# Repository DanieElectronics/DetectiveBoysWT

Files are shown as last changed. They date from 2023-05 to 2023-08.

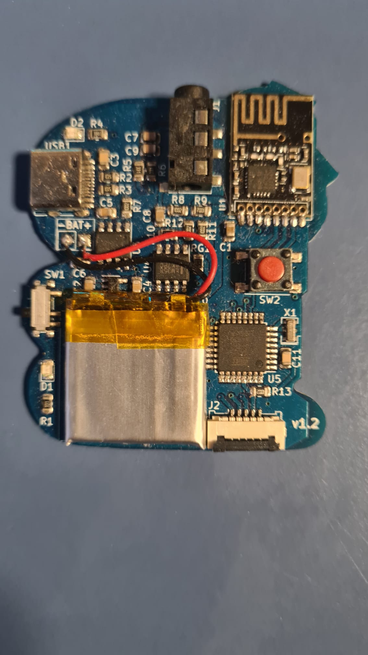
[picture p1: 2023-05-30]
board_front.jpg

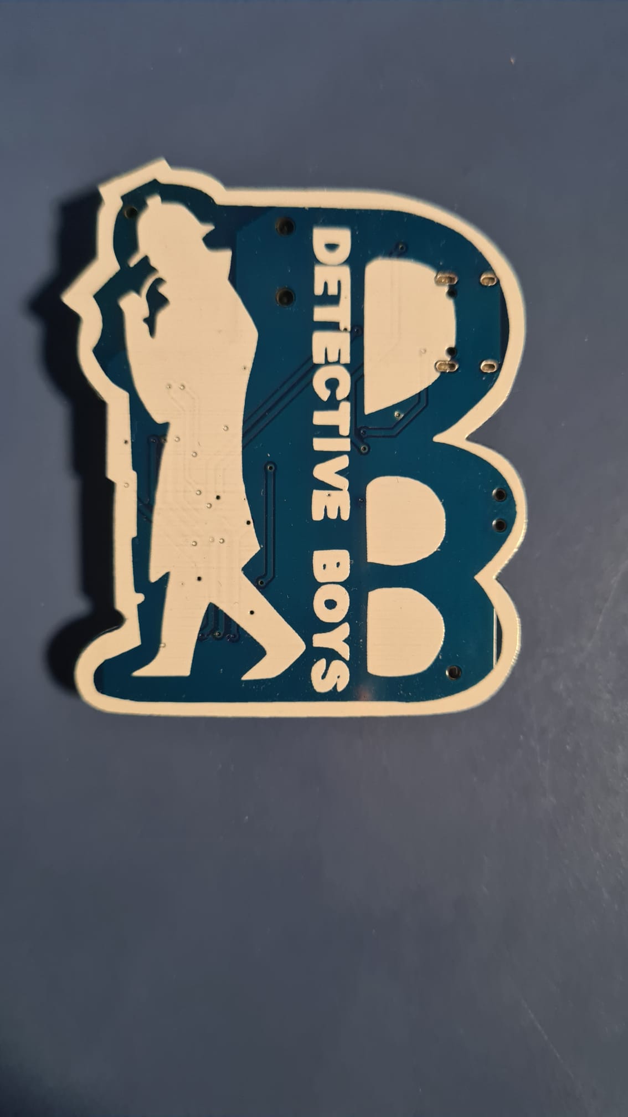
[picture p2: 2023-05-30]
board_back.jpg

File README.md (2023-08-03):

# Detective Boys walkie talkie pin badge
Walkie talkie radio pin badge inspired by Detective Conan anime series using a custom PCB and an ATMEGA328P (Arduino) microcontroller.		
Integrated rechargable battery, can be charged using any USB-C cable and USB power supply.

This repository includes the fabrication files for mounting the boards and assembling the components (gerber files, bill of materials, pick and place), as long as the code used for the microcontroller.
Keep in mind there are external components to be mounted/soldered as the battery or radio module.

## How to use
To use the walkie talkie plug any headphones with microphone into the 3.5mm audio jack, then flick the switch on the left side of the board and the LED will light up.
Press and hold the button on the board to transmit audio, all the near walkie talkies will receive and play the audio.
No pairing or previous configuration is needed.

The battery lasts around 4 hours and it can be recharged by plugging an USB-C cable, any cable or power source is compatible.
When the battery is charging, the LED near the USB connector will light up, when the battery is fully charged the LED will turn off again.
The headphones used may affect on the audio quality, try using different headphones to compare the results.

## Technical description
This project uses ATMEGA328P microcontroller on a custom PCB, the microcontrollers sends the audio data using NRF24L01 radio modules,
ATMEGA328P microcontroller works at 3.3V 8MHz, you can program it using Arduino IDE and an external programmer like USBTinyISP.

The NRF24L01 radio module is a SMD version suitable for small sized boards, it has a maximum range of 100 meters.

The LiPo battery is directly soldered into the battery terminals of the board, recommended capacity is 100-150mAh.

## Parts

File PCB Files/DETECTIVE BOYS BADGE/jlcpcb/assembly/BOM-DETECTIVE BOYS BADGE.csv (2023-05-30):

Comment | Designator | Footprint | LCSC
1k | R10,R4 | R_0805_2012Metric | C115316
ATmega328P-A | U5 | TQFP-32_7x7mm_P0.8mm | C14877
USB_C 31-M-12 | USB1 | USB_C_Receptacle_HRO_TYPE-C-31-M-12 | C165948
10uF | C1,C2,C4,C5,C6,C8 | C_0805_2012Metric | C17024
330nF | C7,C9 | C_0805_2012Metric | C1740
10k | R11,R12,R13,R7,R8,R9 | R_0805_2012Metric | C17414
470k | RG1 | R_0805_2012Metric | C17709
SPDT_PCM12 | SW1 | SW_SPDT_PCM12 | C221841
Pushbutton | SW2 | SW_SPST_PTS645 | C221871
330 | R1,R5,R6 | R_0805_2012Metric | C25306
ICSP | J2 | Molex_200528-0050_1x05-1MP_P1.00mm_Horizontal | C262360
TP4056 | U3 | SOIC-8-1EP_3.9x4.9mm_P1.27mm_EP2.29x3mm | C2763448
5.1k | R2,R3 | R_0805_2012Metric | C27834
Resonator 8MHz | X1 | Resonator_SMD_Murata_CSTxExxV-3Pin_3.0x1.1mm | C341522
MIC5205-3.3YM5 | U2 | SOT-23-5 | C37970
LED_0805 | D1,D2 | LED_0805_2012Metric | C434431
100nF | C10,C11,C3 | C_0805_2012Metric | C476766
Jack 3.5mm | J1 | Jack_3.5mm_PJ320D_Horizontal | C521460
LM358 | U4 | SOP-8_3.9x4.9mm_P1.27mm | C7950
NRF24L01_Breakout | U1 | NRF24L01_Mini
LiPo 100mAh | BT1 | PinSocket_1x02_P2.54mm_Vertical

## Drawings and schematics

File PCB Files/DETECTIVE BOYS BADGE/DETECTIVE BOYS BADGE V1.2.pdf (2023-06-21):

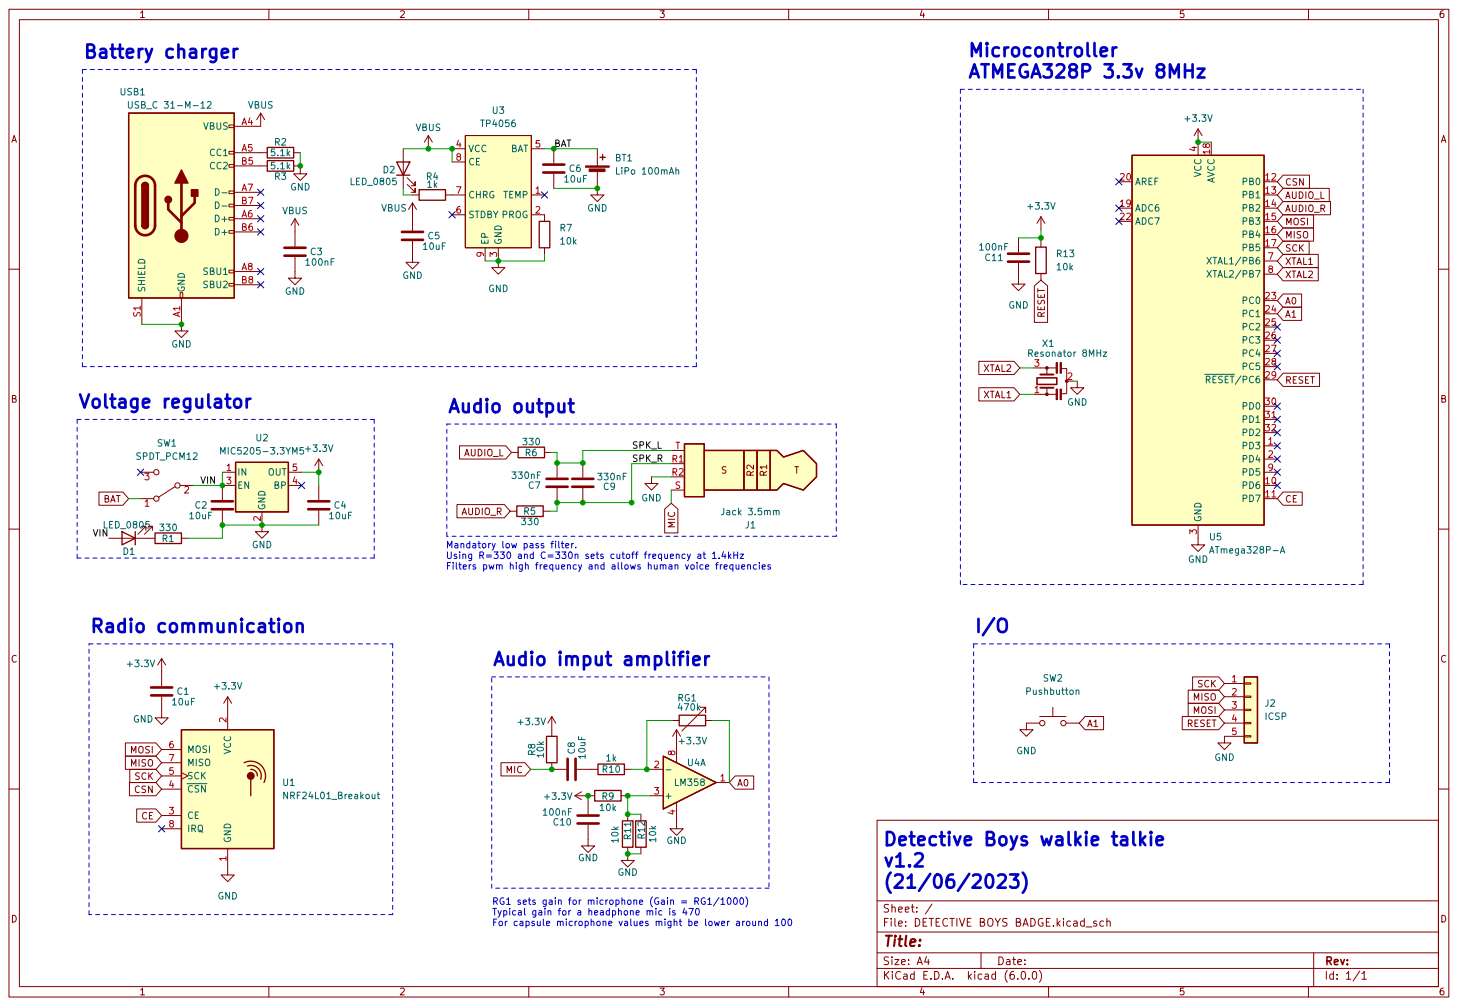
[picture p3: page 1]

3 VCC 4 BAT 5 STDBY 6 CHRG 7 CE 8 EP

2 EN 3 BP 4 OUT 5 U2 MIC5205-3.3YM5 RESET MIC

Mandatory low pass filter.
Using R=330 and C=330n sets cutoff frequency at 1.4kHz
Filters pwm high frequency and allows human voice frequencies

2 CE 3 ~{CSN} 4 SCK 5 MOSI 6 MISO 7

RG1 sets gain for microphone (Gain = RG1/1000)
Typical gain for a headphone mic is 470
For capsule microphone values might be lower around 100

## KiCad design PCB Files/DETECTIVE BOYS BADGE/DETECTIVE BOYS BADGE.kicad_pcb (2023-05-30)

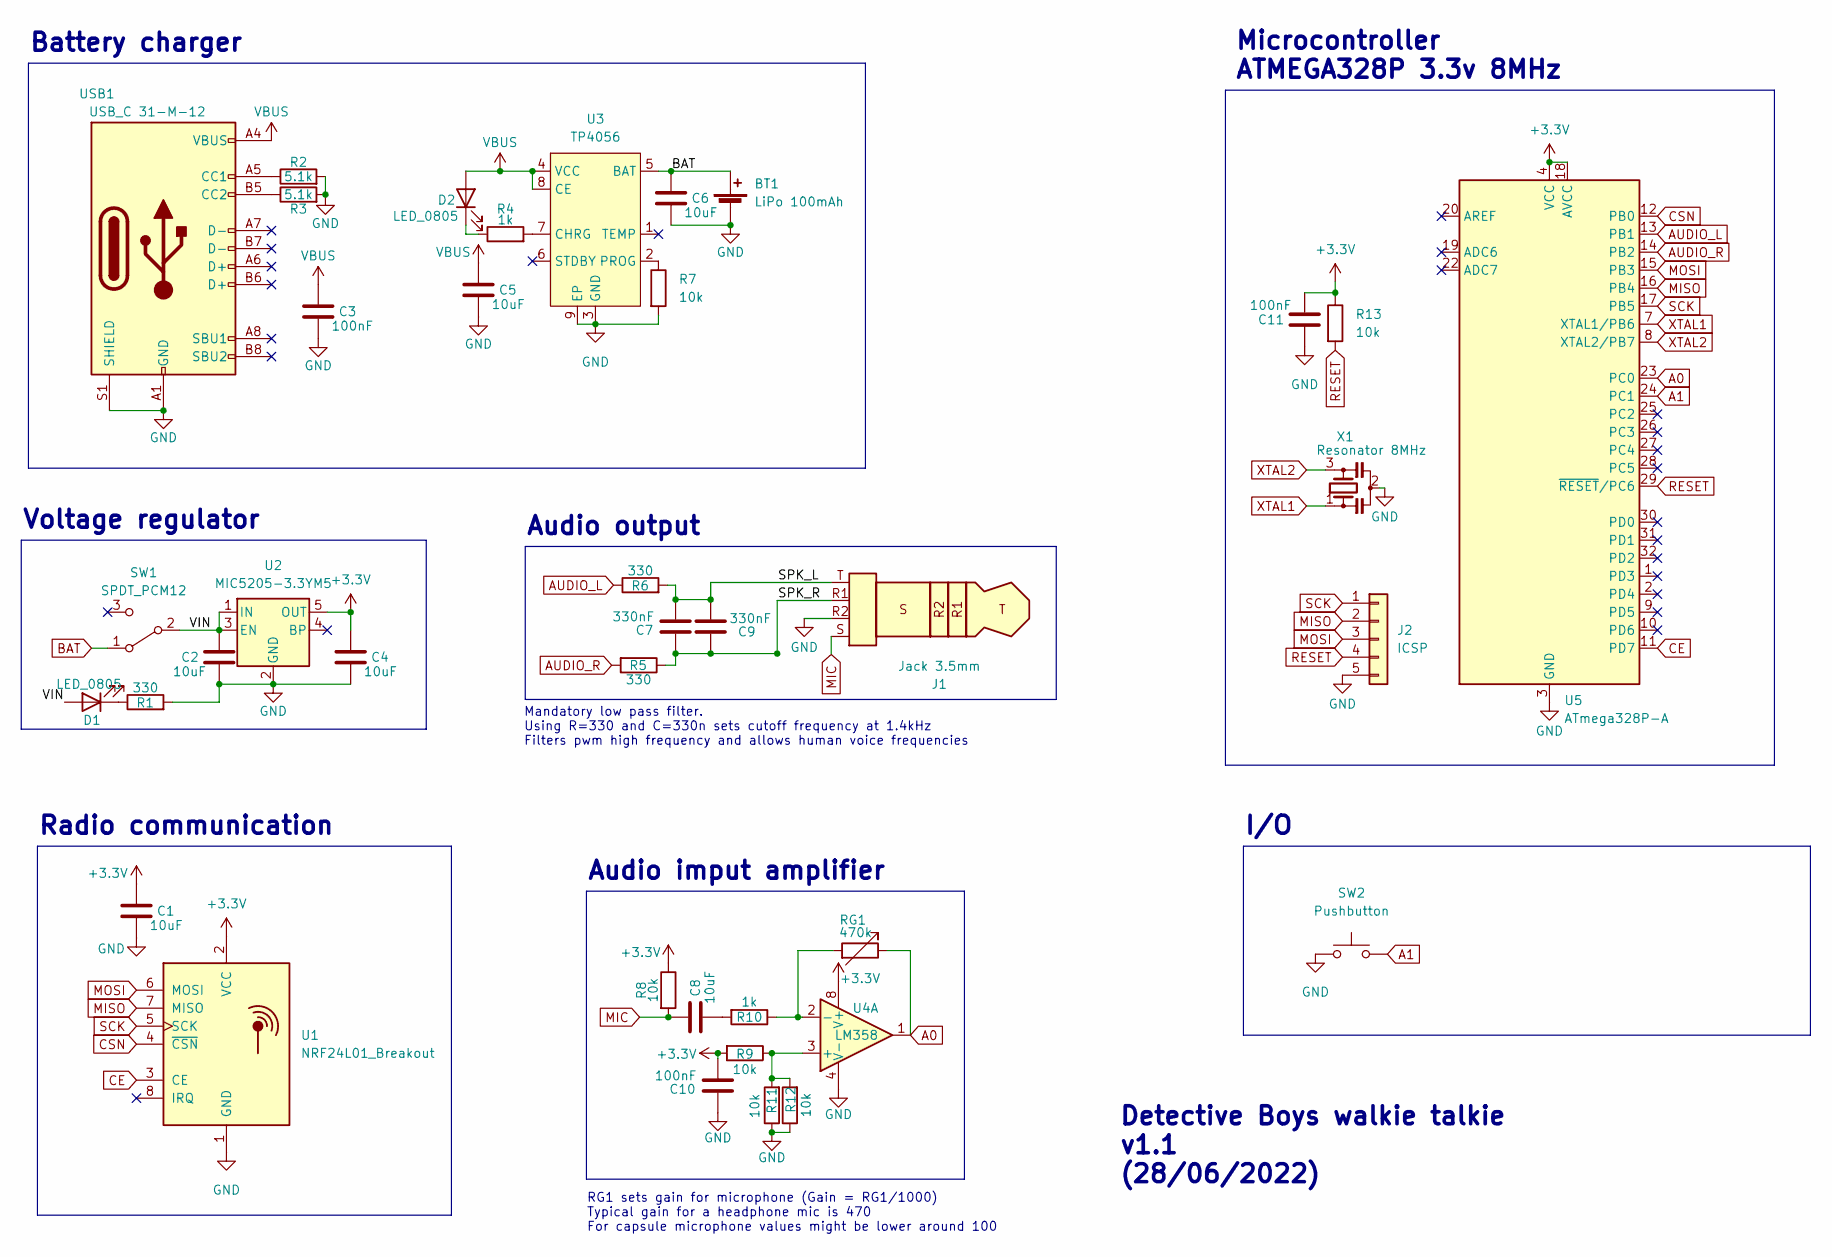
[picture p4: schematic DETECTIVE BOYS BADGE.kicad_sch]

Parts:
BT1: LiPo 100mAh; PinSocket_1x02_P2.54mm_Vertical
C1, C2, C4, C5, C6, C8: 10uF; C_0805_2012Metric
C3, C10, C11: 100nF; C_0805_2012Metric
C7, C9: 330nF; C_0805_2012Metric
D1, D2: LED_0805; LED_0805_2012Metric
J1: Jack 3.5mm; Jack_3.5mm_PJ320D_Horizontal
J2: ICSP; Molex_200528-0050_1x05-1MP_P1.00mm_Horizontal
R1, R5, R6: 330; R_0805_2012Metric
R2, R3: 5.1k; R_0805_2012Metric
R4, R10: 1k; R_0805_2012Metric
R7, R8, R9, R11, R12, R13: 10k; R_0805_2012Metric
RG1: 470k; R_0805_2012Metric
SW1: SPDT_PCM12; SW_SPDT_PCM12
SW2: Pushbutton; SW_SPST_PTS645
U1: NRF24L01_Breakout; NRF24L01_Mini
U2: MIC5205-3.3YM5; SOT-23-5
U3: TP4056; SOIC-8-1EP_3.9x4.9mm_P1.27mm_EP2.29x3mm
U4: LM358; SOP-8_3.9x4.9mm_P1.27mm
U5: ATmega328P-A; TQFP-32_7x7mm_P0.8mm
USB1: USB_C 31-M-12; USB_C_Receptacle_HRO_TYPE-C-31-M-12
X1: Resonator 8MHz; Resonator_SMD_Murata_CSTxExxV-3Pin_3.0x1.1mm

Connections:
+3V3: C1.1, C4.1, C10.2, C11.2, R8.1, R9.2, R13.1, U1.2 (VCC), U2.5 (OUT), U4.8 (V+), U5.4 (VCC), U5.6 (VCC), U5.18 (AVCC)
/SPK_L: C7.2, C9.2, J1.T, R6.2
/SPK_R: C7.1, C9.1, J1.R1, R5.1
/VIN: C2.1, D1.2 (A), SW1.2 (B), U2.1 (IN), U2.3 (EN)
A0: RG1.1, U4.1, U5.23 (PC0)
A1: SW2.2, U5.24 (PC1)
AUDIO_L: R6.1, U5.13 (PB1)
AUDIO_R: R5.2, U5.14 (PB2)
BAT: BT1.1 (+), C6.1, SW1.1 (A), U3.5 (BAT)
CE: U1.3 (CE), U5.11 (PD7)
CSN: U1.4 (~CSN), U5.12 (PB0)
GND: BT1.2 (-), C1.2, C2.2, C3.2, C4.2, C5.2, C6.2, C10.1, C11.1, J1.R2, J2.5, R1.2, R2.2, R3.2, R7.2, R11.1, R12.1, SW2.1, U1.1 (GND), U2.2 (GND), U3.3 (GND), U3.9 (EP), U4.4 (V-), U5.3 (GND), U5.5 (GND), U5.21 (GND), USB1.A1 (GND), USB1.A12 (GND), USB1.B1 (GND), USB1.B12 (GND), USB1.S1 (SHIELD), X1.2
MIC: C8.1, J1.S, R8.2
MISO: J2.2, U1.7 (MISO), U5.16 (PB4)
MOSI: J2.3, U1.6 (MOSI), U5.15 (PB3)
unnamed: C8.2, R10.2
unnamed: D1.1 (K), R1.1
unnamed: D2.1 (K), R4.1
unnamed: R2.1, USB1.A5 (CC1)
unnamed: R3.1, USB1.B5 (CC2)
unnamed: R4.2, U3.7 (CHRG)
unnamed: R7.1, U3.2 (PROG)
unnamed: R10.1, RG1.2, U4.2 (-)
unnamed: R9.1, R11.2, R12.2, U4.3 (+)
RESET: J2.4, R13.2, U5.29 (~RESET/PC6)
SCK: J2.1, U1.5 (SCK), U5.17 (PB5)
VBUS: C3.1, C5.1, D2.2 (A), U3.4 (VCC), U3.8 (CE), USB1.A4 (VBUS), USB1.A9 (VBUS), USB1.B4 (VBUS), USB1.B9 (VBUS)
XTAL1: U5.7 (XTAL1/PB6), X1.1
XTAL2: U5.8 (XTAL2/PB7), X1.3

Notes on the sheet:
Battery charger
Audio imput amplifier
Mandatory low pass filter. Using R=330 and C=330n sets cutoff frequency at 1.4kHz Filters pwm high frequency and allows human voice frequencies
I/O
RG1 sets gain for microphone (Gain = RG1/1000) Typical gain for a headphone mic is 470 For capsule microphone values might be lower around 100
Radio communication
Microcontroller ATMEGA328P 3.3v 8MHz
Audio output
Detective Boys walkie talkie v1.1 (28/06/2022)
Voltage regulator

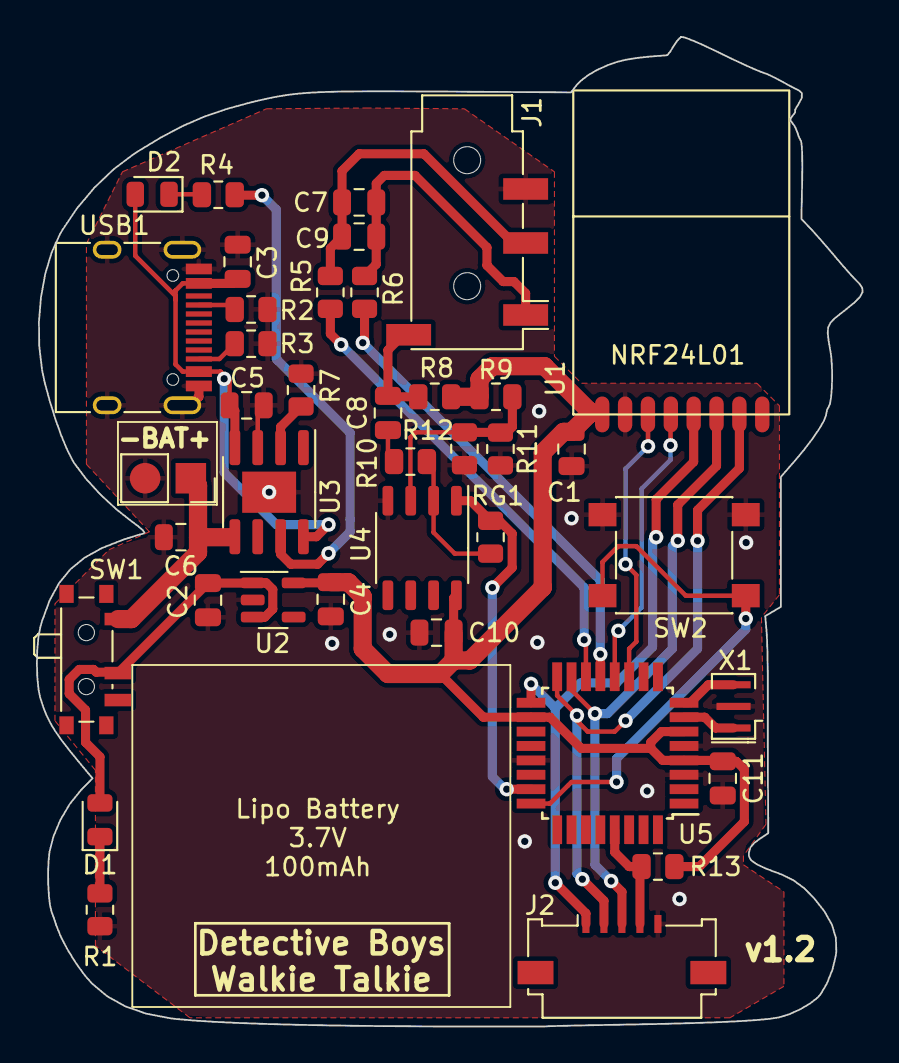
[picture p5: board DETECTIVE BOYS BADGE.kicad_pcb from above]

Board: 2 copper layers, 45.9 x 55.0 mm, 39 parts (0 on the bottom side), 29 nets.

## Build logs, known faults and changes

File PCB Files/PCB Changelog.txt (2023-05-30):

- v1.0
Initial version

- v1.1
Corrected the LM358P (U4) wrong connections, now the microphone pre-amp circuit works as intended.
Adjusted the pads footprint of NRF24L01 making it easier to solder and preventing solder bridges.
The SW1 switch NO terminal is no longer connected to USB power, this allows to turn off the board when charging.

- v1.2
Added a flexPCB connector on the edge of the board connected to the ICSP pins, making easier to program the ATMEGA328P.
The battery terminals footprint is now only on one side of the board, preventing accidental short-circuit on the bottom side.
Moved some components to allow more space for the LiPo battery.
Changed the values of components C7,C9 R5,R6, adjusting the values for filtering the audio output.

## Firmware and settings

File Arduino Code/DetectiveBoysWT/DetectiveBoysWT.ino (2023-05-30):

//// Detective Boys Walkie Talkie ////

/* 
  This software uses RF24Audio library to send audio data between NRF24L01 radio modules
  This code runs on an ATMEGA328P microcontroller at 3.3v & 8MHZ
  Use Arduino Pro Mini 3.3v 8MHz at board selection in Arduino IDE
  You must burn the bootloader before uploading the code
*/

#include "RF24.h"
#include <SPI.h>
#include "RF24Audio.h"

RF24 radio(7,8);                // Set radio up using pins 7 (CE) 8 (CS)
RF24Audio rfAudio(radio,1);     // Set up the audio using the radio, and set to radio number 0.

void setup() {          

  rfAudio.begin();              // Initialize the library.
  rfAudio.setVolume(4);         // Set volume at 50% (4/7)

}

void loop() {
  rfAudio.handleButtons();
}





/* Documentation and References:

References:
All Library documentation: http://tmrh20.github.io/
New (2014) RF24 Audio Library: https://github.com/TMRh20/RF24Audio
Optimized (2014) RF24 Lib Source Code: https://github.com/TMRh20/RF24 
Optimized (2014) RF24 Network Lib: https://github.com/TMRh20/RF24Network

*/

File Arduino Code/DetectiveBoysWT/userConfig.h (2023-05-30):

/**
 * @file userConfig.h
 *
 * macros for customization of RF24Audio
 */

/************  MANDATORY User Variables  ************/
/**
 * @brief The sample rate to use for transferring audio samples
 *
 * Maximum Range: Sample rate 16000, RF_SPEED RF24_250KBPS <br>
 * Maximum Quality: Sample rate 44000, RF_SPEED RF24_2MBPS
 * @note 44khz+ sample rate requires 8-bits per sample
 */
#define SAMPLE_RATE 16000

/**
 * @brief configure the RF data rate
 *
 * These are not limits, just a guide:
 * - RF24_250KBPS will do 13-20khz+ sample rate
 * - RF24_1MBPS up to 24-44khz+
 * - RF24_2MBPS for higher.
 */
#define RF_SPEED RF24_250KBPS

/** @brief The pin that analog readings will be taken from (microphone pin) */
#define ANALOG_PIN A0

/************  OverRides  ************/

//10-bit audio requires more bandwidth. A 20khz sample rate will need 25KB/S transfer rate, which is about max for 250kbps data rate.
//With a 32khz sample rate, the volume can be set to -1 to shift the sample down to 9-bit, which is the highest the timers can handle at 32khz
#define tenBit       // Enable 10-bit samples   Note: 44khz+ sample rate requires 8-bits per sample

//#define speakerPin 9 // If using a non-standard board, override the timer1 pins
//#define speakerPin 10

/**
 * @brief Indicator pin
 *
 * Using pin 6 on Uno enables audio visualization. Pin 13 on Mega 2560 (TIMER0 COMPA)
 * @note The pin number cannot be changed.
 */
#define ENABLE_LED

/************  Optional/Advanced User Variables  ************/


/** Button pin to trigger recording & transmission */
#define TX_PIN A1

/** Pin for external volume control */
#define VOL_UP_PIN A2

/** Pin for external volume control */
#define VOL_DN_PIN A3

/** Pin for externally triggering remote recording */
#define REMOTE_TX_PIN A4

/** Pin for externally stopping remote recording (needs timeout enabled) */
#define REMOTE_RX_PIN 4

/** The size of the memory buffer to use. Not really configurable (set to maximum by default). */
#define buffSize 32

//#define speakerTX               // Whether to output to speaker while transmitting
//#define oversampling            // Oversampling is recommended for low sample rates only. This only affects playback.
//#define RX_ONLY
//#define TX_ONLY // Not functional yet


/************  Automated pin selections, override by defining above  ************/

#if defined(__AVR_ATmega1280__) || defined(__AVR_ATmega2560__) || (__AVR_ATmega32U4__) || (__AVR_AT90USB646__) || defined(__AVR_AT90USB1286__) || (__AVR_ATmega128__) ||defined(__AVR_ATmega1281__)||defined(__AVR_ATmega2561__)
    #define rampMega

    // Speaker pin selection for mega etc
    #if !defined (speakerPin)
        #define speakerPin 11   // The pins to output audio on. (11,12 on Mega 2560)
    #endif

    #if !defined (speakerPin2)
        #define speakerPin2 12
    #endif

    #if defined (ENABLE_LED)
        #define ledPin 13
    #endif

#else

    //Speaker selection for Uno,Nano, etc
    #if !defined (speakerPin)
        /** The pin used to output audio on UNO */
        #define speakerPin 9
    #endif

    #if !defined (speakerPin2)
        /** The pin used to output audio on Nano */
        #define speakerPin2 10
    #endif

    #if defined (ENABLE_LED)
        #define ledPin 6
    #endif
#endif


//********Radio Defines ****************************
/** Radio pipe addresses for the 2 nodes to communicate. */
const uint64_t pipes[14] =
{
    0xABCDABCD71LL,
    0x544d52687CLL,
    0x544d526832LL,
    0x544d52683CLL,
    0x544d526846LL,
    0x544d526850LL,
    0x544d52685ALL,
    0x544d526820LL,
    0x544d52686ELL,
    0x544d52684BLL,
    0x544d526841LL,
    0x544d526855LL,
    0x544d52685FLL,
    0x544d526869LL
};

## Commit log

2022-06-27 Initial version
    Modified version of RF24Audio minimal program with some changes to make it work with NRF24L01 mini module and ATMEGA328P-AU at 3.3V / 8MHz.
    RF24Audio config: Sample Rate 18000, Transmission speed 250kbps, Ten bit sampling
2022-06-27 PCB version v1.0
    Kicad Project with schematic and pcb files, includes BOM.
    Minor mistakes to be corrected in v1.1 including the audio pre-amp circuit and some component values
    [BOM DB BADGE.csv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]
2022-06-28 Updated PCB version to v1.1
    Fixed some schematic error designs at audio amplifier circuit, modified NRF24 mini footprint to easier placement.
    [DETECTIVE BOYS BADGE-B_Cu.gbr, DETECTIVE BOYS BADGE-B_Mask.gbr, DETECTIVE BOYS BADGE-B_Paste.gbr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]
2022-06-30 Updated bill of materials v1.1
    [BILL OF MATERIALS v1.1.csv]
2023-05-30 Updated PCB files to v1.2
    Improved circuit board to v1.2 -
    Added a flexPCB connector on the edge of the board connected to the ICSP pins, making easier to program the ATMEGA328P.
    The battery terminals footprint is now only on one side of the board, preventing accidental short-circuit on the bottom side.
    Moved some components to allow more space for the LiPo battery.
    Changed the values of components C7,C9 R5,R6, adjusting the values for filtering the audio output.
    [BOM-DETECTIVE BOYS BADGE.csv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]
2023-05-30 Updated PCB (v1.2)
    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
    [BILL OF MATERIALS v1.1.csv, BOM-DETECTIVE BOYS BADGE.csv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]
2023-05-30 Updated Arduino Code
    Set the Sampling rate of audio to 16000
2023-06-21 Updated Schematic PDF file
    [DETECTIVE BOYS BADGE.kicad_sch]
